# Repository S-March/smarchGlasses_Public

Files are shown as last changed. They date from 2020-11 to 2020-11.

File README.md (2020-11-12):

# smarchGlasses_Public

At the end of the summer I was walking around town soaking in the sun while trying to avoid people (because, well, pandemic). 

As I typed in my next destination to my phone and started following the map, I realized I wasn't really enjoying the sights or the world around me. I was hyper focused on my phone screen and watching myself on the map, making sure I didn't miss a turn. 

While staring at the little blue dot, Ferris Bueller, in all his infinite wisdom spoke up in my head.

"Life moves pretty fast. If you don't stop and look around once in a while, you could miss it."

It was at that moment, I decided that I wanted to make some smart sunglasses that gave me turn-by-turn directions!

For future projects and progress pictures, follow me on instagram @SamsonMarch

smarchWatch

## Other Useful Links
To download the SDK for the DA14531, you can [click this link](https://support.dialog-semiconductor.com/system/files/restricted/SDK_6.0.14.1114.zip)

If you want to order PCBs from the same place I did, you can [click this link](https://www.pcbway.com/project/shareproject/smarchGlasses.html).

For more info on the build process and a blog describing the process, [click here](https://imgur.com/gallery/8lY43kp).

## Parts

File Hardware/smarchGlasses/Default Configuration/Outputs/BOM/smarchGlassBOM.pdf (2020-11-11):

Part | Quantity | Designator | Description
10kΩ | 7 | R1, R3, R4, R5, R13, R14, R15 | 0402 Resistor
10uF | 3 | C2, C6, C8 | 0402 Capacitor
4.7uF | 3 | C3, C4, C5 | 0402 Capacitor
PMZ550UNEYL | 3 | Q3, Q4, Q5 | PMZ550UNEYL N-Channel 30V 590mA (Ta) 310mW (Ta), 1.67W (Tc) Surface Mount DFN1006-3
100Ω | 2 | R11, R12 | 0402 Resistor
1uF | 2 | C1, C9 | 0402 Capacitor
5.1MΩ | 2 | R9, R10 | 0402 Resistor
CIGT201610EH2R2MNE | 2 | L1, L2 | CIGT201610EH2R2MNE 2.2µH Unshielded Thin Film Inductor 2.5A 87mOhm Max 0806 (2016 Metric)
100nF | 1 | C7 | 0402 Capacitor
2.2kΩ | 1 | R8 | 0402 Resistor
200Ω | 1 | R2 | 0402 Resistor
330Ω | 1 | R7 | 0402 Resistor
66.5kΩ | 1 | R6 | 0402 Resistor
APTF1616LSEEZGKQBKC | 1 | D1 | APTF1616LSEEZGKQBKC Red, Green, Blue (RGB) 621nm Red, 525nm Green, 465nm Blue LED Indication - Discrete 1.8V Red, 2.7V Green, 2.7V Blue 0606 (1616 Metric)
BQ29700DSER | 1 | U5 | Battery Battery Protection IC Lithium-Ion/Polymer 6-WSON (1.5x1.5)
BSS84AKM,315 | 1 | Q1 | BSS84AKM,315 MOSFET P-CH 50V SOT883
D5V0L1B2LP4-7B | 1 | D2 | D5V0L1B2LP4-7B 14V Clamp 6A (8/20µs) Ipp Tvs Diode Surface Mount X2-DFN1006-2
DA14531 | 1 | U1 | DA14531 IC RF TxRx + MCU Bluetooth Bluetooth v5.1 2.4GHz 24-WFQFN, FC
ECH8693R | 1 | Q2 | Mosfet Array 2 N-Channel (Dual) Common Drain 24V 14A 1.4W Surface Mount SOT-28FL/ECH8
ECS-320-8-37B-CKY | 1 | X1 | ECS-320-8-37B-CKY CRYSTAL 32.0000MHZ 8PF SMD
LIR1220 | 1 | BAT1 | LIR1220 Battery
LIS3DH | 1 | U6 | LIS3DH ACCEL 2-16G I2C/SPI 16LGA
LM3671 | 1 | U4 | LM3671 IC REG BUCK 3.3V 0.6A SYNC 5USMD
MCP73831T-2ACI/MC | 1 | U3 | MCP73831T-2ACI/MC Charger IC Lithium-Ion/Polymer
PCA9570GMH | 1 | U7 | PCA9570GMH I/O Expander 4 I²C, SMBus 100kHz 8-XQFN (1.6x1.6)
TC2030-CTX-NL | 1 | P1 | TC2030-CTX-NL Tag Connect Cable
W25X20CLUXIG | 1 | U2 | W25X20CLUXIG FLASH Memory IC 2Mb (256K x 8) SPI 104MHz 8-USON (2x3)

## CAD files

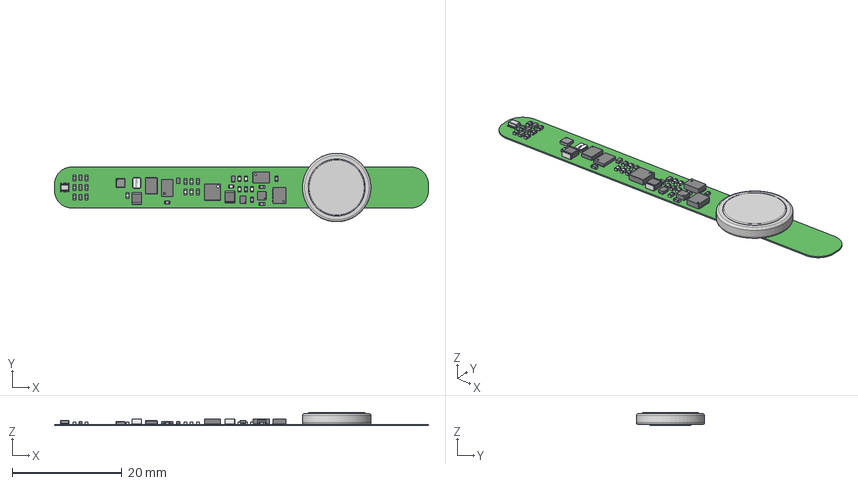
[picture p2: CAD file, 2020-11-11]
Hardware/smarchGlasses/Default Configuration/Outputs/ExportSTEP/smarchGlasses_V1.step
68.3 x 12.5 x 2.39 mm
Board
LIR1220
PCA9570GMH
Extruded x 72
bigPin x 4
smallPine x 8
APTF1616
Open_CASCADE_STEP_translator_6.8_27.1.1 x 2
Open_CASCADE_STEP_translator_6.8_27.1.2 x 2
Open_CASCADE_STEP_translator_6.8_27.2.1 x 3
Open_CASCADE_STEP_translator_6.8_23.1
Open_CASCADE_STEP_translator_6.8_23.2.1
Open_CASCADE_STEP_translator_6.8_23.3.1 x 8
DA14531
Open_CASCADE_STEP_translator_6.8_15.1
Open_CASCADE_STEP_translator_6.8_15.2.1
Open_CASCADE_STEP_translator_6.8_15.3.1 x 8
Open_CASCADE_STEP_translator_6.8_27.1
Thermal_Shape
Open_CASCADE_STEP_translator_6.8_27.4.1 x 8
Open_CASCADE_STEP_translator_6.8_46.1
Open_CASCADE_STEP_translator_6.8_46.2.1
ball x 6
Open_CASCADE_STEP_translator_6.8_9.1
Open_CASCADE_STEP_translator_6.8_9.2.1
Open_CASCADE_STEP_translator_6.8_9.3.1 x 6
LIS3DH
ECS-320-8-37B-CKY
D5V0L1B2LP4-7B

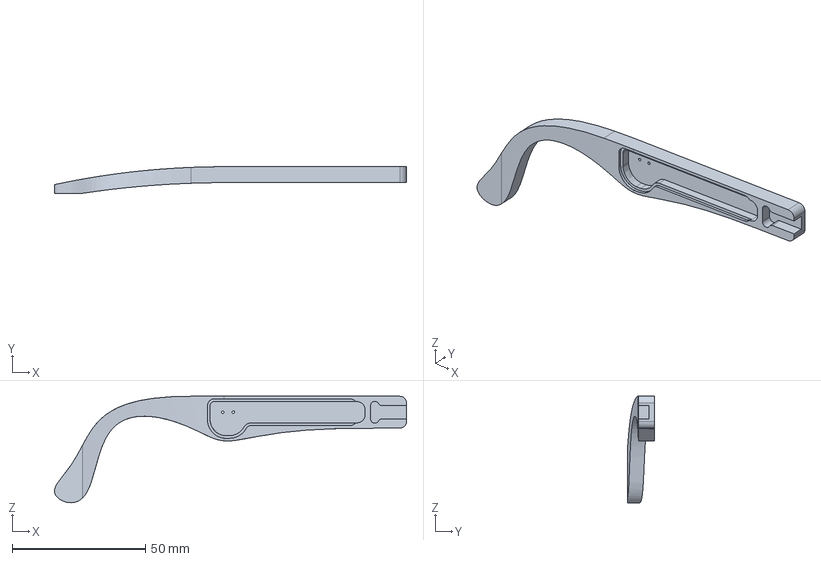
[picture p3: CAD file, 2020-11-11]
Mechanical/smarchGlasses/framePieces/leftLeg.step
132.2 x 10.0 x 40.0 mm

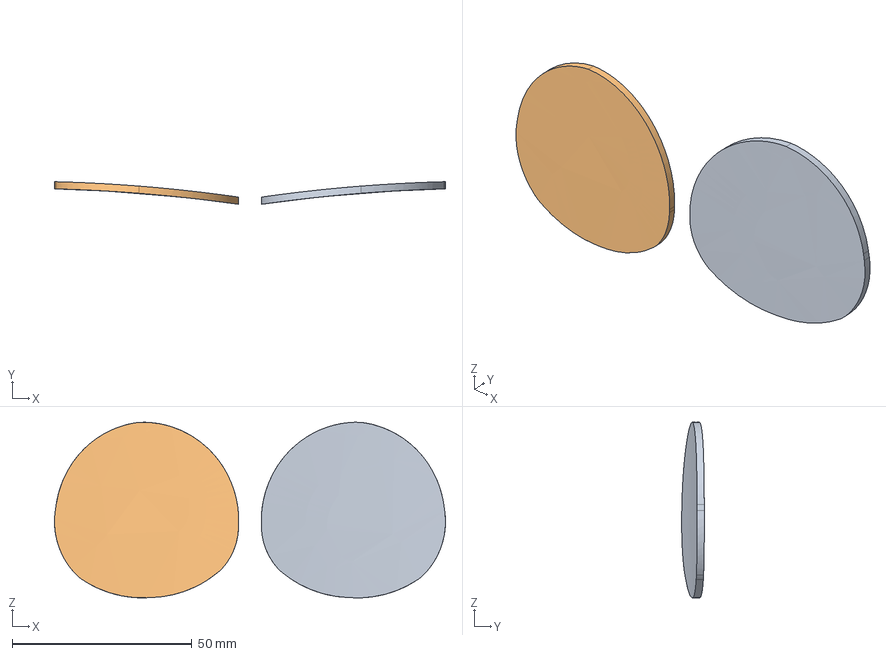
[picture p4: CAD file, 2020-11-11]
Mechanical/smarchGlasses/lensPieces/lensCAD.step
108.7 x 6.30 x 48.8 mm

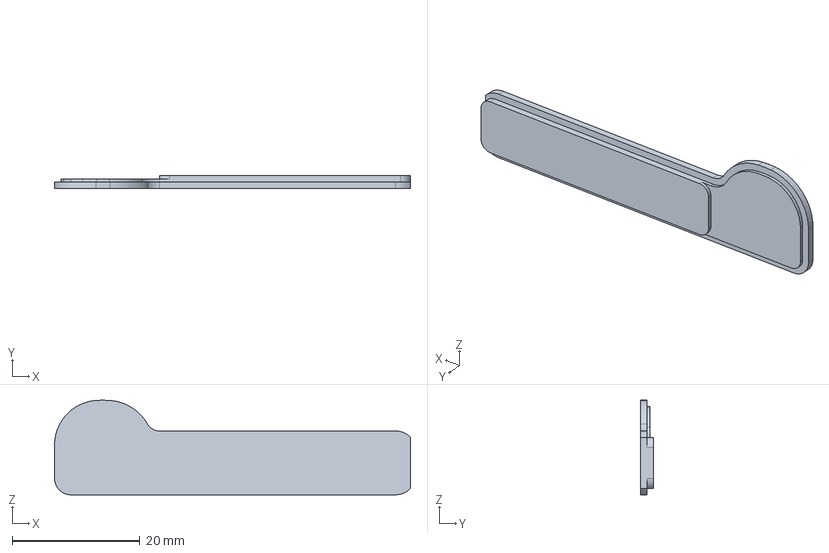
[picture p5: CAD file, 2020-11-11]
Mechanical/smarchGlasses/framePieces/rightPanel.step
55.8 x 2.00 x 14.8 mm

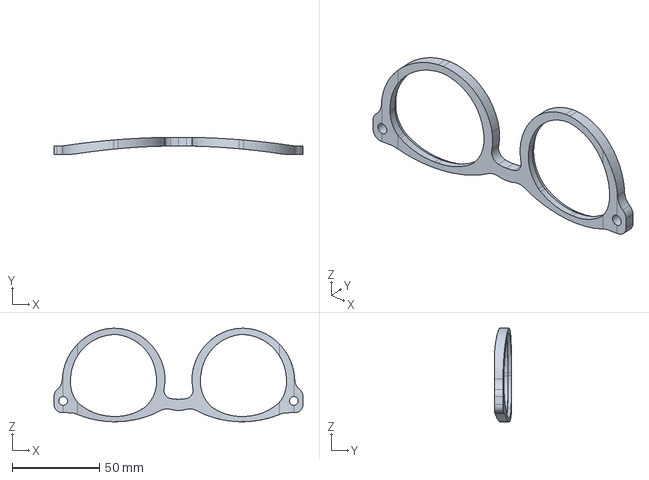
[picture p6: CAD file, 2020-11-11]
Mechanical/smarchGlasses/framePieces/frontFrame.step
142.5 x 10.0 x 53.6 mm

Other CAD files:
Mechanical/smarchGlasses/framePieces/rightLeg.step
Mechanical/smarchGlasses/framePieces/leftPanel.step

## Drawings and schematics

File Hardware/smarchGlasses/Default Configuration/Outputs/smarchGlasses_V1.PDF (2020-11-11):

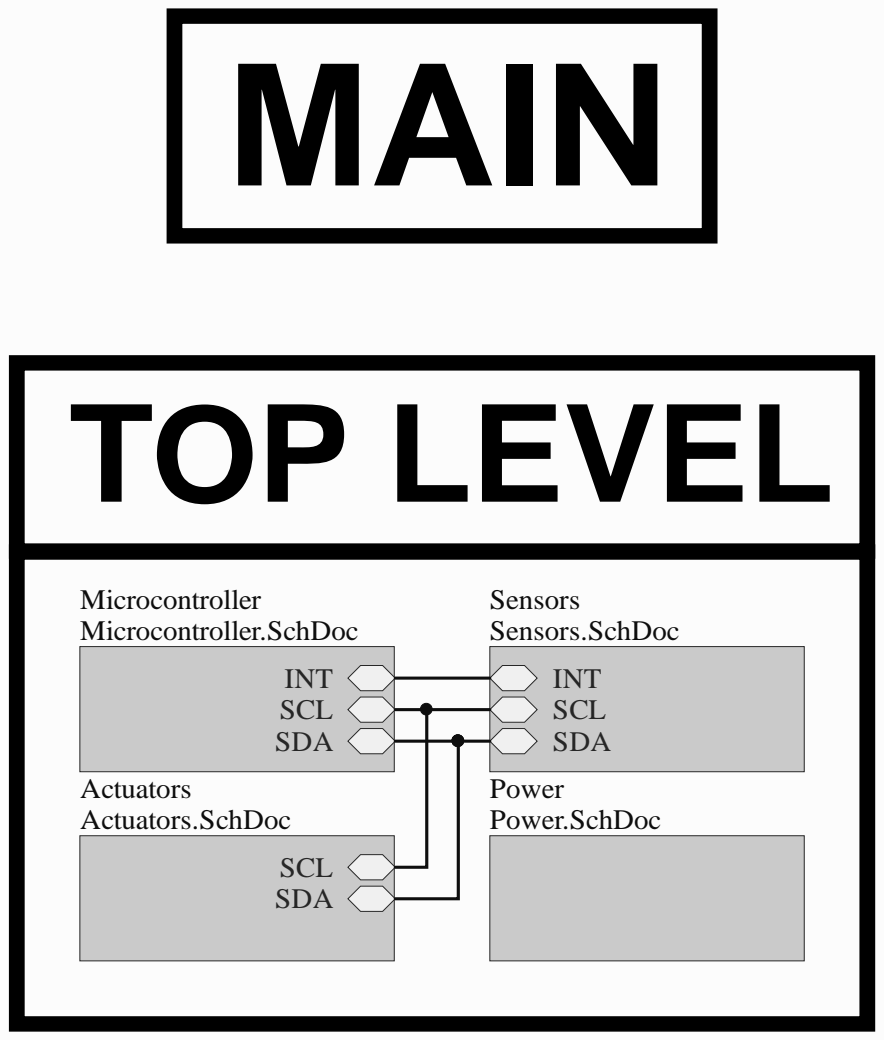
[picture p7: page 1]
TOP LEVEL

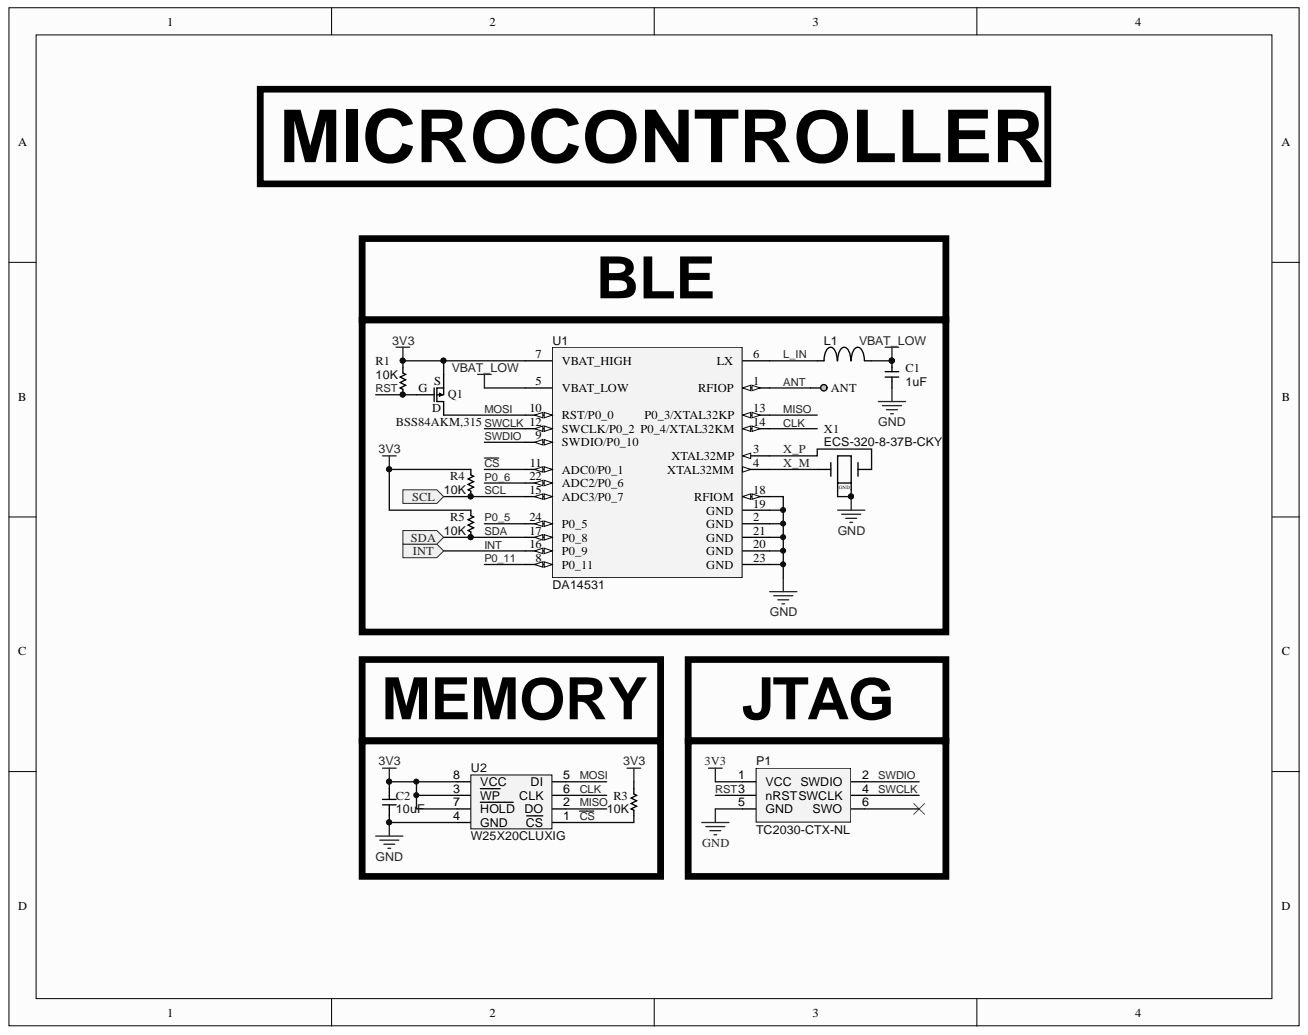
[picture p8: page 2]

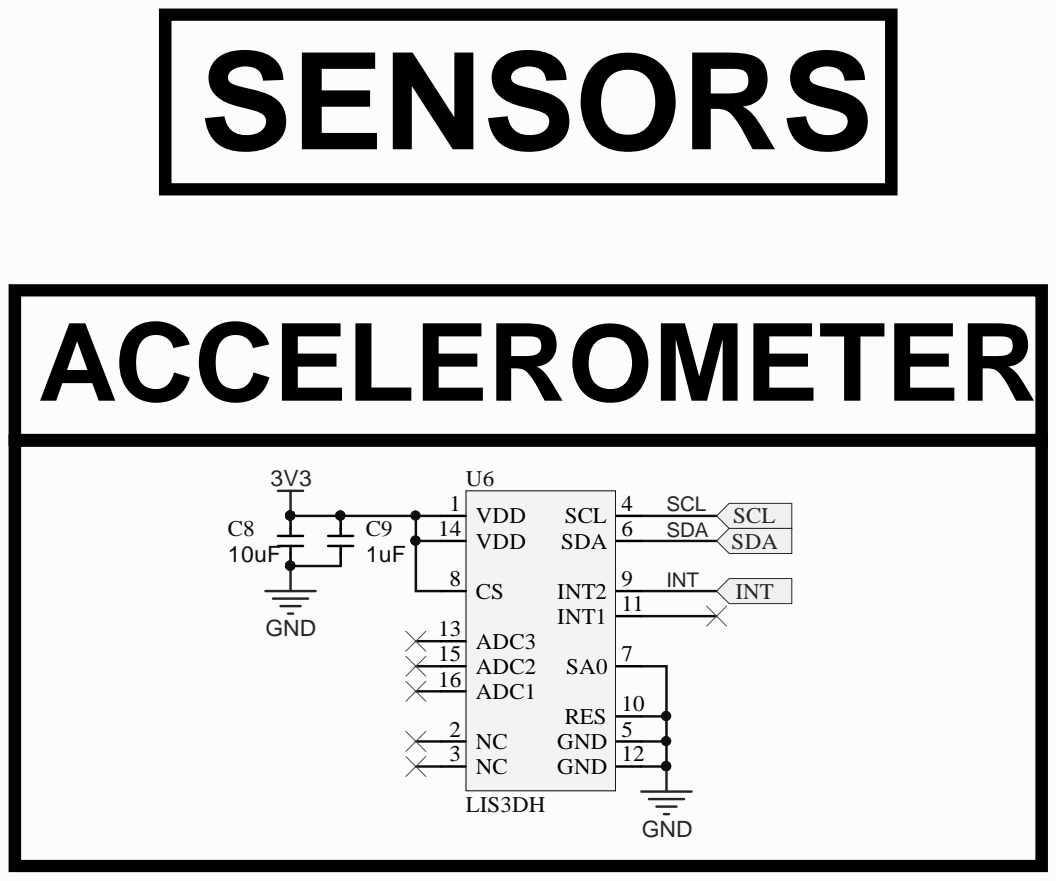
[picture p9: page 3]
3V3 GND; ACCELEROMETER SCL; VDD 14; ADC2 15; ADC1 16 U6 LIS3DH

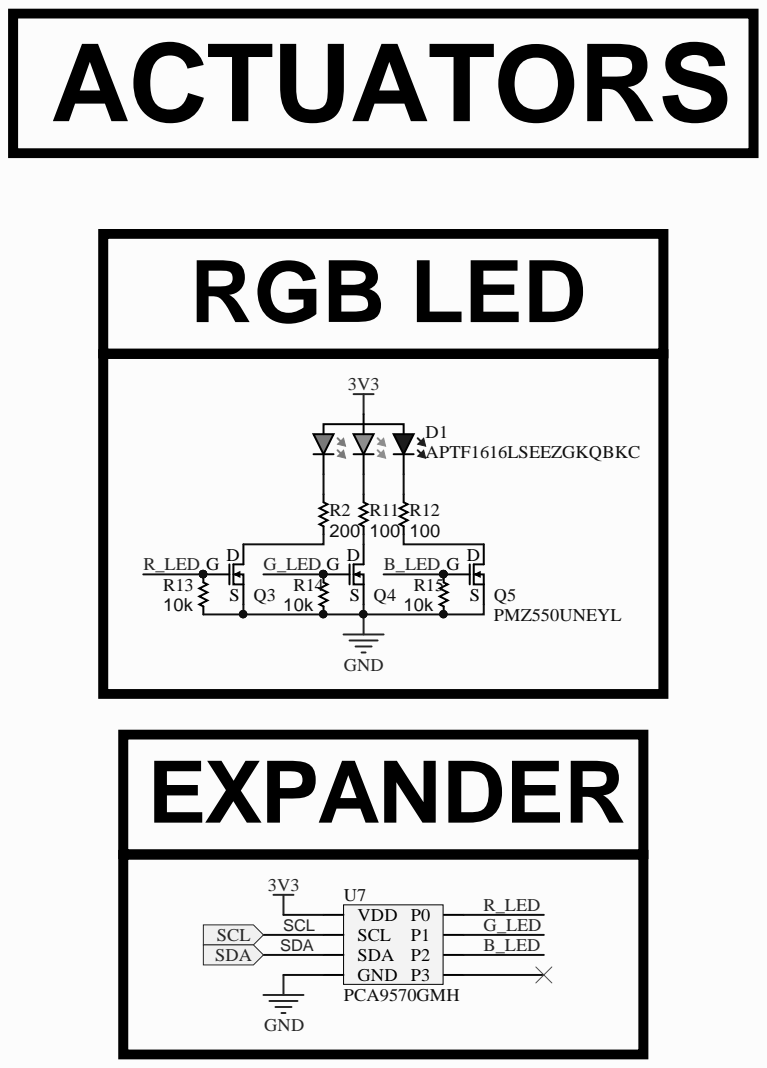
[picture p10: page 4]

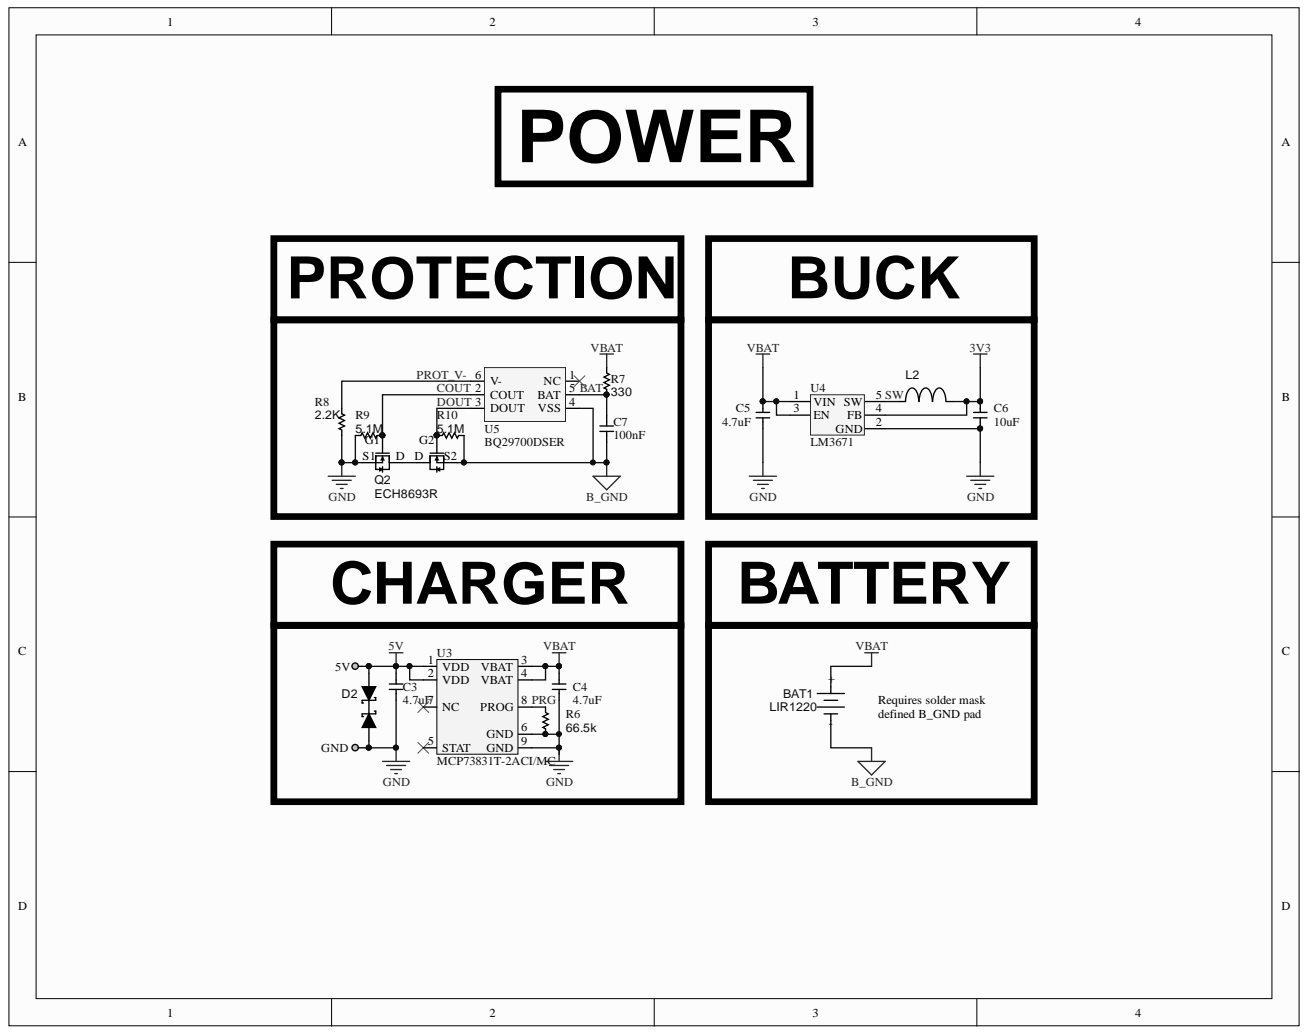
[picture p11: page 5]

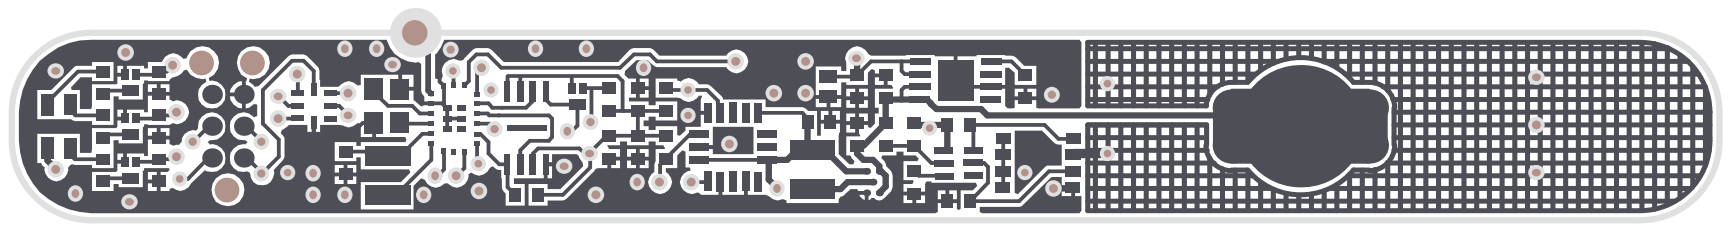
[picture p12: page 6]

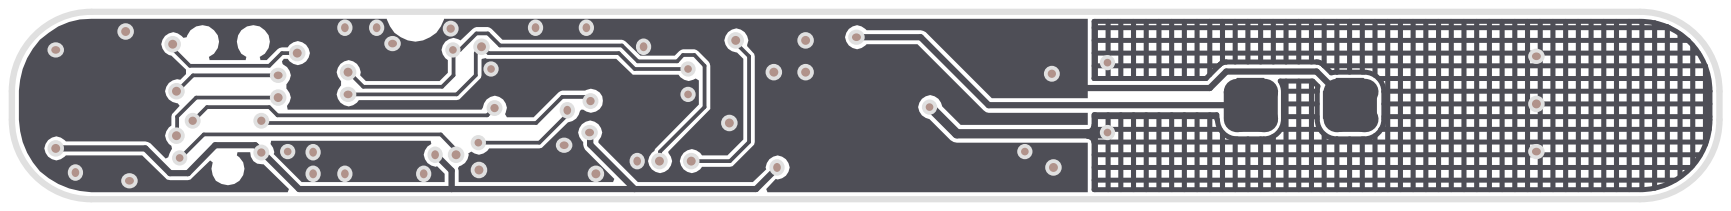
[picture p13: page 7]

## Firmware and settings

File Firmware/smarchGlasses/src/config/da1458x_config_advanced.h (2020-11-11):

/**
 ****************************************************************************************
 *
 * @file da1458x_config_advanced.h
 *
 * @brief Advanced compile configuration file.
 *
 * Copyright (C) 2014-2020 Dialog Semiconductor.
 * This computer program includes Confidential, Proprietary Information
 * of Dialog Semiconductor. All Rights Reserved.
 *
 ****************************************************************************************
 */

#ifndef _DA1458X_CONFIG_ADVANCED_H_
#define _DA1458X_CONFIG_ADVANCED_H_

#include "da1458x_stack_config.h"

#if !defined (__DA14531__)

/****************************************************************************************************************/
/* Low Power clock selection.                                                                                   */
/*      -LP_CLK_XTAL32      External XTAL32K oscillator                                                         */
/*      -LP_CLK_RCX20       Internal RCX clock                                                                  */
/*      -LP_CLK_FROM_OTP    Use the selection in the corresponding field of OTP Header                          */
/****************************************************************************************************************/
#define CFG_LP_CLK              LP_CLK_XTAL32

/****************************************************************************************************************/
/* If defined the application uses a hardcoded value for XTAL16M trimming. Should be disabled for devices       */
/* where XTAL16M is calibrated and trim value is stored in OTP.                                                 */
/* Important note. The hardcoded value is the average value of the trimming values giving the optimal results   */
/* for DA14585 DK devices. May not be applicable in other designs                                               */
/****************************************************************************************************************/
#define CFG_USE_DEFAULT_XTAL16M_TRIM_VALUE_IF_NOT_CALIBRATED

/****************************************************************************************************************/
/* Periodic wakeup period to poll GTL iface. Time in msec.                                                      */
/****************************************************************************************************************/
#define CFG_MAX_SLEEP_DURATION_PERIODIC_WAKEUP_MS                  500  // 0.5s

/****************************************************************************************************************/
/* Periodic wakeup period if GTL iface is not enabled. Time in msec.                                            */
/****************************************************************************************************************/
#define CFG_MAX_SLEEP_DURATION_EXTERNAL_WAKEUP_MS              600000  // 600s

/****************************************************************************************************************/
/* Wakeup from external processor running host application.                                                     */
/****************************************************************************************************************/
#undef CFG_EXTERNAL_WAKEUP

/****************************************************************************************************************/
/* Wakeup external processor when a message is sent to GTL                                                      */
/****************************************************************************************************************/
#undef CFG_WAKEUP_EXT_PROCESSOR
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

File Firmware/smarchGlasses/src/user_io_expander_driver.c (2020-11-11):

/*
 * INCLUDE FILES
 ****************************************************************************************
 */

#include <stdint.h>
#include <stdbool.h>
#include <string.h>
#include "compiler.h"
#include "ll.h"
#include "user_io_expander_driver.h"
#include "i2c.h"


uint8_t currentIOExpanderState;

 /**
 ****************************************************************************************
 * @brief Initialize I2C IO Expander
 ****************************************************************************************
 */
void i2c_ioExpander_initialize(void)
{
	currentIOExpanderState = 0x00;
	i2c_ioExpander_AllLow();
}
 /**
 ****************************************************************************************
 * @brief Set I2C IO Expander Pin High
 * @param[in] ioExpander_pinNumber    Pin number to set
 * @param[in] ioExpander_HiLo   Whether to set the pin high or low
 ****************************************************************************************
 */
 void i2c_ioExpander_pinSet(uint8_t ioExpander_pinNumber, uint8_t ioExpander_HiLo)
 {
	i2c_abort_t abrt_code;
	if(ioExpander_HiLo)
	{
		currentIOExpanderState |= 1 << ioExpander_pinNumber;
	}
	else
	{
		currentIOExpanderState &= ~(1 << ioExpander_pinNumber);
	}
	//Disable controller to change slave address 
	i2c_set_controller_status(I2C_CONTROLLER_DISABLE);
	while ((i2c_get_controller_status() != I2C_CONTROLLER_DISABLE));
	i2c_set_target_address(IOEXPANDER_ADDRESS);
	i2c_set_controller_status(I2C_CONTROLLER_ENABLE);
	while ((i2c_get_controller_status() != I2C_CONTROLLER_ENABLE));
	i2c_master_transmit_buffer_sync(&currentIOExpanderState,sizeof(currentIOExpanderState),&abrt_code,I2C_F_NONE);
 }
 
 /**
 ****************************************************************************************
 * @brief Set I2C IO Expander All High
 * @param[in] ioExpander_pin    Pin number to set
 ****************************************************************************************
 */
 void i2c_ioExpander_AllHigh(void)
 {
	currentIOExpanderState = 0x0F;
	i2c_abort_t abrt_code;
	//Disable controller to change slave address 
	i2c_set_controller_status(I2C_CONTROLLER_DISABLE);
	while ((i2c_get_controller_status() != I2C_CONTROLLER_DISABLE));
	i2c_set_target_address(IOEXPANDER_ADDRESS);
	i2c_set_controller_status(I2C_CONTROLLER_ENABLE);
	while ((i2c_get_controller_status() != I2C_CONTROLLER_ENABLE));
	i2c_master_transmit_buffer_sync(&currentIOExpanderState,sizeof(currentIOExpanderState),&abrt_code,I2C_F_NONE);
 }
 
  /**
 ****************************************************************************************
 * @brief Set I2C IO Expander All High
 * @param[in] ioExpander_pin    Pin number to set
 ****************************************************************************************
 */
 void i2c_ioExpander_RedHigh(void)
 {
	currentIOExpanderState = 0x01;
	i2c_abort_t abrt_code;
	//Disable controller to change slave address 
	i2c_set_controller_status(I2C_CONTROLLER_DISABLE);
	while ((i2c_get_controller_status() != I2C_CONTROLLER_DISABLE));
	i2c_set_target_address(IOEXPANDER_ADDRESS);
	i2c_set_controller_status(I2C_CONTROLLER_ENABLE);
	while ((i2c_get_controller_status() != I2C_CONTROLLER_ENABLE));
	i2c_master_transmit_buffer_sync(&currentIOExpanderState,sizeof(currentIOExpanderState),&abrt_code,I2C_F_NONE);
 }
 
  /**
 ****************************************************************************************
 * @brief Set I2C IO Expander All High
 * @param[in] ioExpander_pin    Pin number to set
 ****************************************************************************************
 */
 void i2c_ioExpander_GreenHigh(void)
 {
	currentIOExpanderState = 0x02;
	i2c_abort_t abrt_code;
	//Disable controller to change slave address 
	i2c_set_controller_status(I2C_CONTROLLER_DISABLE);
	while ((i2c_get_controller_status() != I2C_CONTROLLER_DISABLE));
	i2c_set_target_address(IOEXPANDER_ADDRESS);
	i2c_set_controller_status(I2C_CONTROLLER_ENABLE);
	while ((i2c_get_controller_status() != I2C_CONTROLLER_ENABLE));
	i2c_master_transmit_buffer_sync(&currentIOExpanderState,sizeof(currentIOExpanderState),&abrt_code,I2C_F_NONE);
 }
 
  /**
 ****************************************************************************************
 * @brief Set I2C IO Expander All High
 * @param[in] ioExpander_pin    Pin number to set
 ****************************************************************************************
 */
 void i2c_ioExpander_BlueHigh(void)
 {
	currentIOExpanderState = 0x04;
	i2c_abort_t abrt_code;
	//Disable controller to change slave address 
	i2c_set_controller_status(I2C_CONTROLLER_DISABLE);
	while ((i2c_get_controller_status() != I2C_CONTROLLER_DISABLE));
	i2c_set_target_address(IOEXPANDER_ADDRESS);
	i2c_set_controller_status(I2C_CONTROLLER_ENABLE);
	while ((i2c_get_controller_status() != I2C_CONTROLLER_ENABLE));
	i2c_master_transmit_buffer_sync(&currentIOExpanderState,sizeof(currentIOExpanderState),&abrt_code,I2C_F_NONE);
 }
 
 
 /**
 ****************************************************************************************
 * @brief Set I2C IO Expander All Low
 * @param[in] ioExpander_pin    Pin number to set
 ****************************************************************************************
 */
 void i2c_ioExpander_AllLow(void)
 {
	currentIOExpanderState = 0x00;
	i2c_abort_t abrt_code;
	//Disable controller to change slave address 
	i2c_set_controller_status(I2C_CONTROLLER_DISABLE);
	while ((i2c_get_controller_status() != I2C_CONTROLLER_DISABLE));
	i2c_set_target_address(IOEXPANDER_ADDRESS);
	i2c_set_controller_status(I2C_CONTROLLER_ENABLE);
	while ((i2c_get_controller_status() != I2C_CONTROLLER_ENABLE));
	i2c_master_transmit_buffer_sync(&currentIOExpanderState,sizeof(currentIOExpanderState),&abrt_code,I2C_F_NONE);
 }

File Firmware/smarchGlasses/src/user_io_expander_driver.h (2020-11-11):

#ifndef _I2C_IOEXPANDER_H_
#define _I2C_IOEXPANDER_H_
/*
 * INCLUDE FILES
 ****************************************************************************************
 */

#include <stdint.h>
#include <stdbool.h>
#include "i2c.h"
/*
 * DEFINES
 ****************************************************************************************
 */ 
 #define IOEXPANDER_ADDRESS 0x24
 
/// Expander Pin Number
typedef enum
{
    I2C_IOEXPANDER_P0 = 0,
    I2C_IOEXPANDER_P1 = 1,
    I2C_IOEXPANDER_P2 = 2,
    I2C_IOEXPANDER_P3 = 3,
} i2c_ioExpander_portPins;

/// Expander High Low
typedef enum
{
    I2C_IOEXPANDER_LOW = 0,
    I2C_IOEXPANDER_HIGH = 1,
} i2c_ioExpander_HiLo;

/*
 * FUNCTION DECLARATIONS
 ****************************************************************************************
 */

 /**
 ****************************************************************************************
 * @brief Initialize I2C IO Expander
 ****************************************************************************************
 */
void i2c_ioExpander_initialize(void);


 /**
 ****************************************************************************************
 * @brief Set I2C IO Expander Pin High
 * @param[in] ioExpander_pinNumber    Pin number to set
 * @param[in] ioExpander_HiLo   Whether to set the pin high or low
 ****************************************************************************************
 */
 void i2c_ioExpander_pinSet(uint8_t ioExpander_pinNumber, uint8_t ioExpander_HiLo);
 
 /**
 ****************************************************************************************
 * @brief Set I2C IO Expander All High
 * @param[in] ioExpander_pin    Pin number to set
 ****************************************************************************************
 */
 void i2c_ioExpander_AllHigh(void);
 
  /**
 ****************************************************************************************
 * @brief Set I2C IO Expander All High
 * @param[in] ioExpander_pin    Pin number to set
 ****************************************************************************************
 */
 void i2c_ioExpander_RedHigh(void);
 
  /**
 ****************************************************************************************
 * @brief Set I2C IO Expander All High
 * @param[in] ioExpander_pin    Pin number to set
 ****************************************************************************************
 */
 void i2c_ioExpander_GreenHigh(void);
 
  /**
 ****************************************************************************************
 * @brief Set I2C IO Expander All High
 * @param[in] ioExpander_pin    Pin number to set
 ****************************************************************************************
 */
 void i2c_ioExpander_BlueHigh(void);
 
 
 /**
 ****************************************************************************************
 * @brief Set I2C IO Expander All Low
 * @param[in] ioExpander_pin    Pin number to set
 ****************************************************************************************
 */
 void i2c_ioExpander_AllLow(void);
 #endif // _I2C_IOEXPANDER_H_

///@}
///@}

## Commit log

2020-11-11 Initial hardware commit
    [Actuators.SchDoc, BOM_PartType-smarchGlasses_V1.csv, Main.SchDoc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]
2020-11-11 Initial mechanical commit
    [frontFrame.step, leftLeg.step, leftPanel.step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]
2020-11-11 Initial software commit
    [Actuators.SchDoc, BOM_PartType-smarchGlasses_V1.csv, Main.SchDoc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]
